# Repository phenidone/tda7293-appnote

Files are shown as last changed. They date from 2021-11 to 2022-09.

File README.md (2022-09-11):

# Stereo TDA7293

This is a PCB design for a stereo amplifier, using a TDA7293 for each channel.

## Power

The board requires 36+36V DC for 8R loads.  Filtering caps are included, but 
a bridge rectifier is not as this is expected to be used with a switching supply.

## Unmute

The muting circuits are controlled via an opto-isolated input.  Provide 
5-24VDC on the UNMUTE port to enable the amplifiers.  This port allows the
amplifier to be put into a standby/mute mode, e.g. while preamplifiers are
booting and power supplies are stabilising.

## Components

Input capacitors shall be film-type box capacitors, 5mm lead pitch.

C3 and C9 should be non-polarised 22uF electrolytics, as high-voltage as will
fit in the footprint (8mm with 3.5mm lead pitch).

All resistors in the signal chain (R1, R2, R3, R13, R14, R15) should be thin-film
metal precision resistors.

Loop-break resistors (R7, R8, R17, R18) can be chosen differently in accordance
with different grounding needs, e.g. where multiple modules are powered from a
single PSU but receiving signal from a third preamplifier board.  Their
selection depends on your ground topology.

The output zobels (R5/C6, R16/C12) are probably only necessary with a TDA7294,
and may be omitted if there is absolutely no chance of shorting the amplifier
leads, e.g. through use of insulated plugs instead of bare wires into screw
terminals.  R5 and R16 should be 2W-rated.

## TDA7294

The board charges the bootstrap capacitor from the OUTPUT pin rather than
the BOOTLOAD pin, so this board will also work unmodified with a TDA7294.
That limits the absolute-max supply voltage to 100V rather than 120V, but
the appropriate level is lower than that anyway unless you have a very high
impedance load.

## License

This hardware design is (C) 2021 William Brodie-Tyrrell and is licensed under 
the CERN OHL; see cern_ohl_v_1_2.pdf

## TRL

Rev.A is tested and working, but has not been subjected to EMI or other
regulatory testing.

Rev.B has been manufactured but not tested.

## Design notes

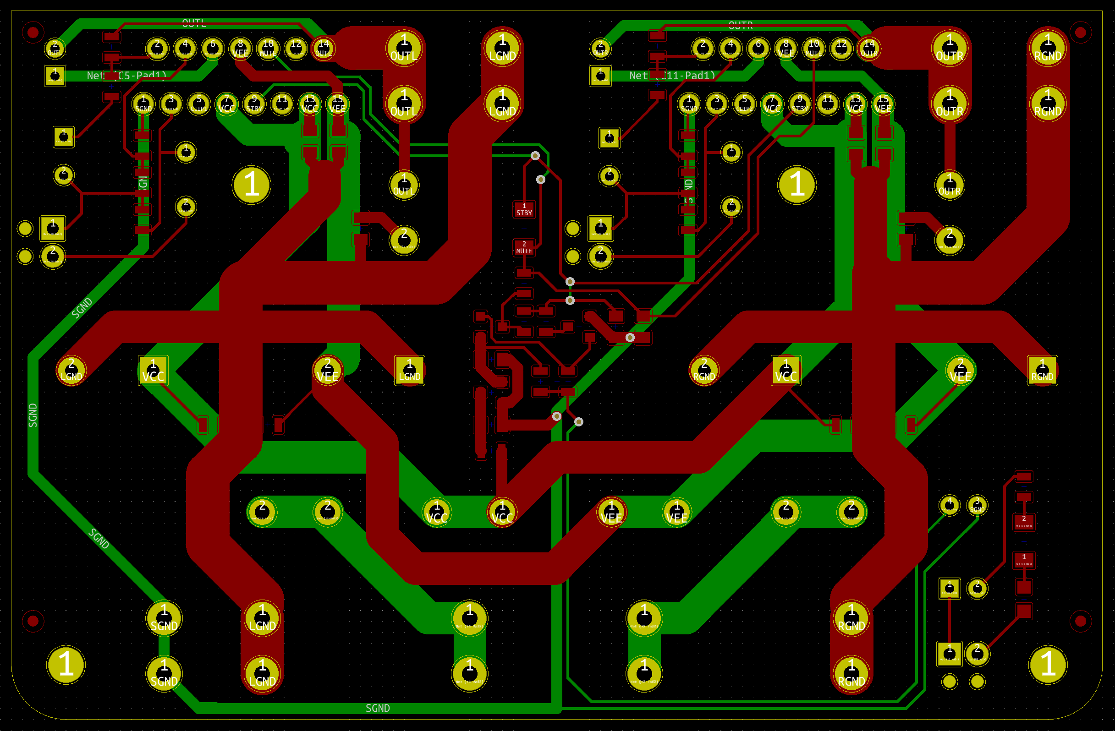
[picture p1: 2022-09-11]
tda7293-layout.png

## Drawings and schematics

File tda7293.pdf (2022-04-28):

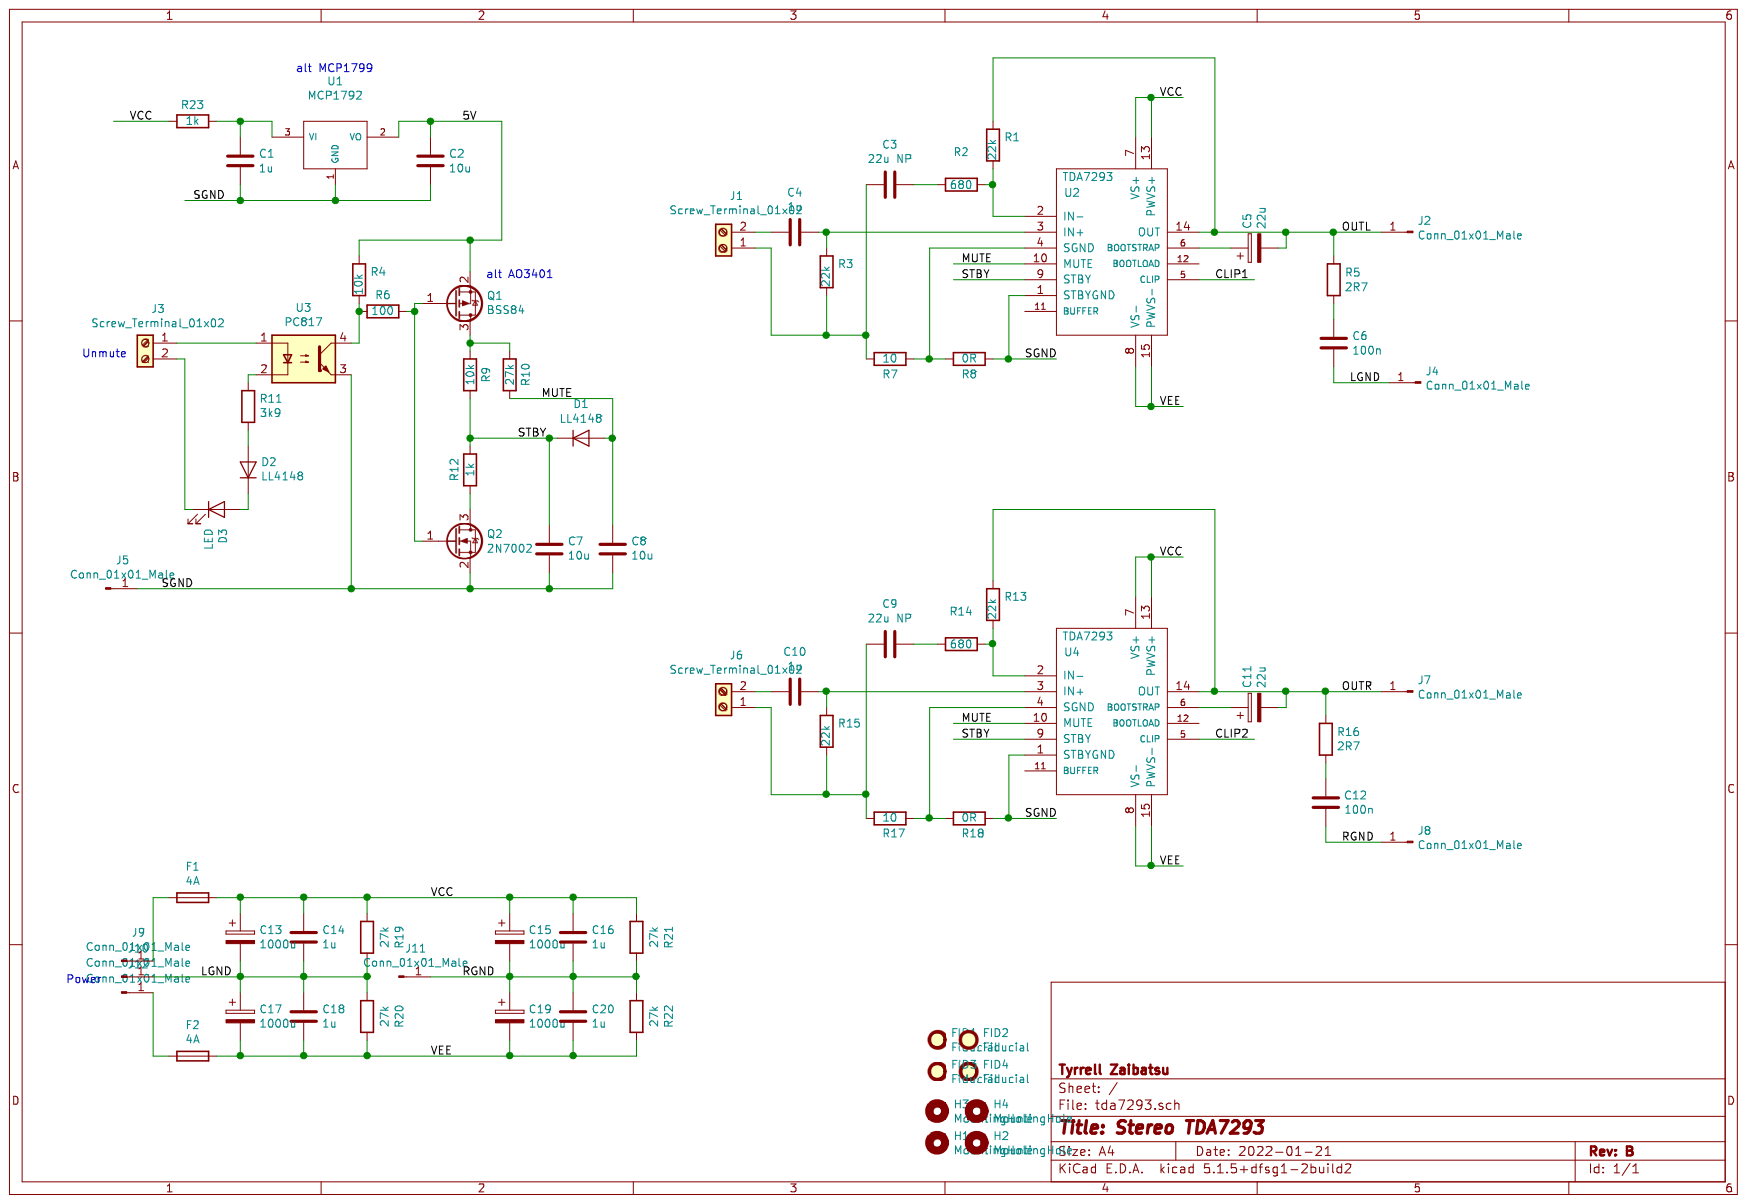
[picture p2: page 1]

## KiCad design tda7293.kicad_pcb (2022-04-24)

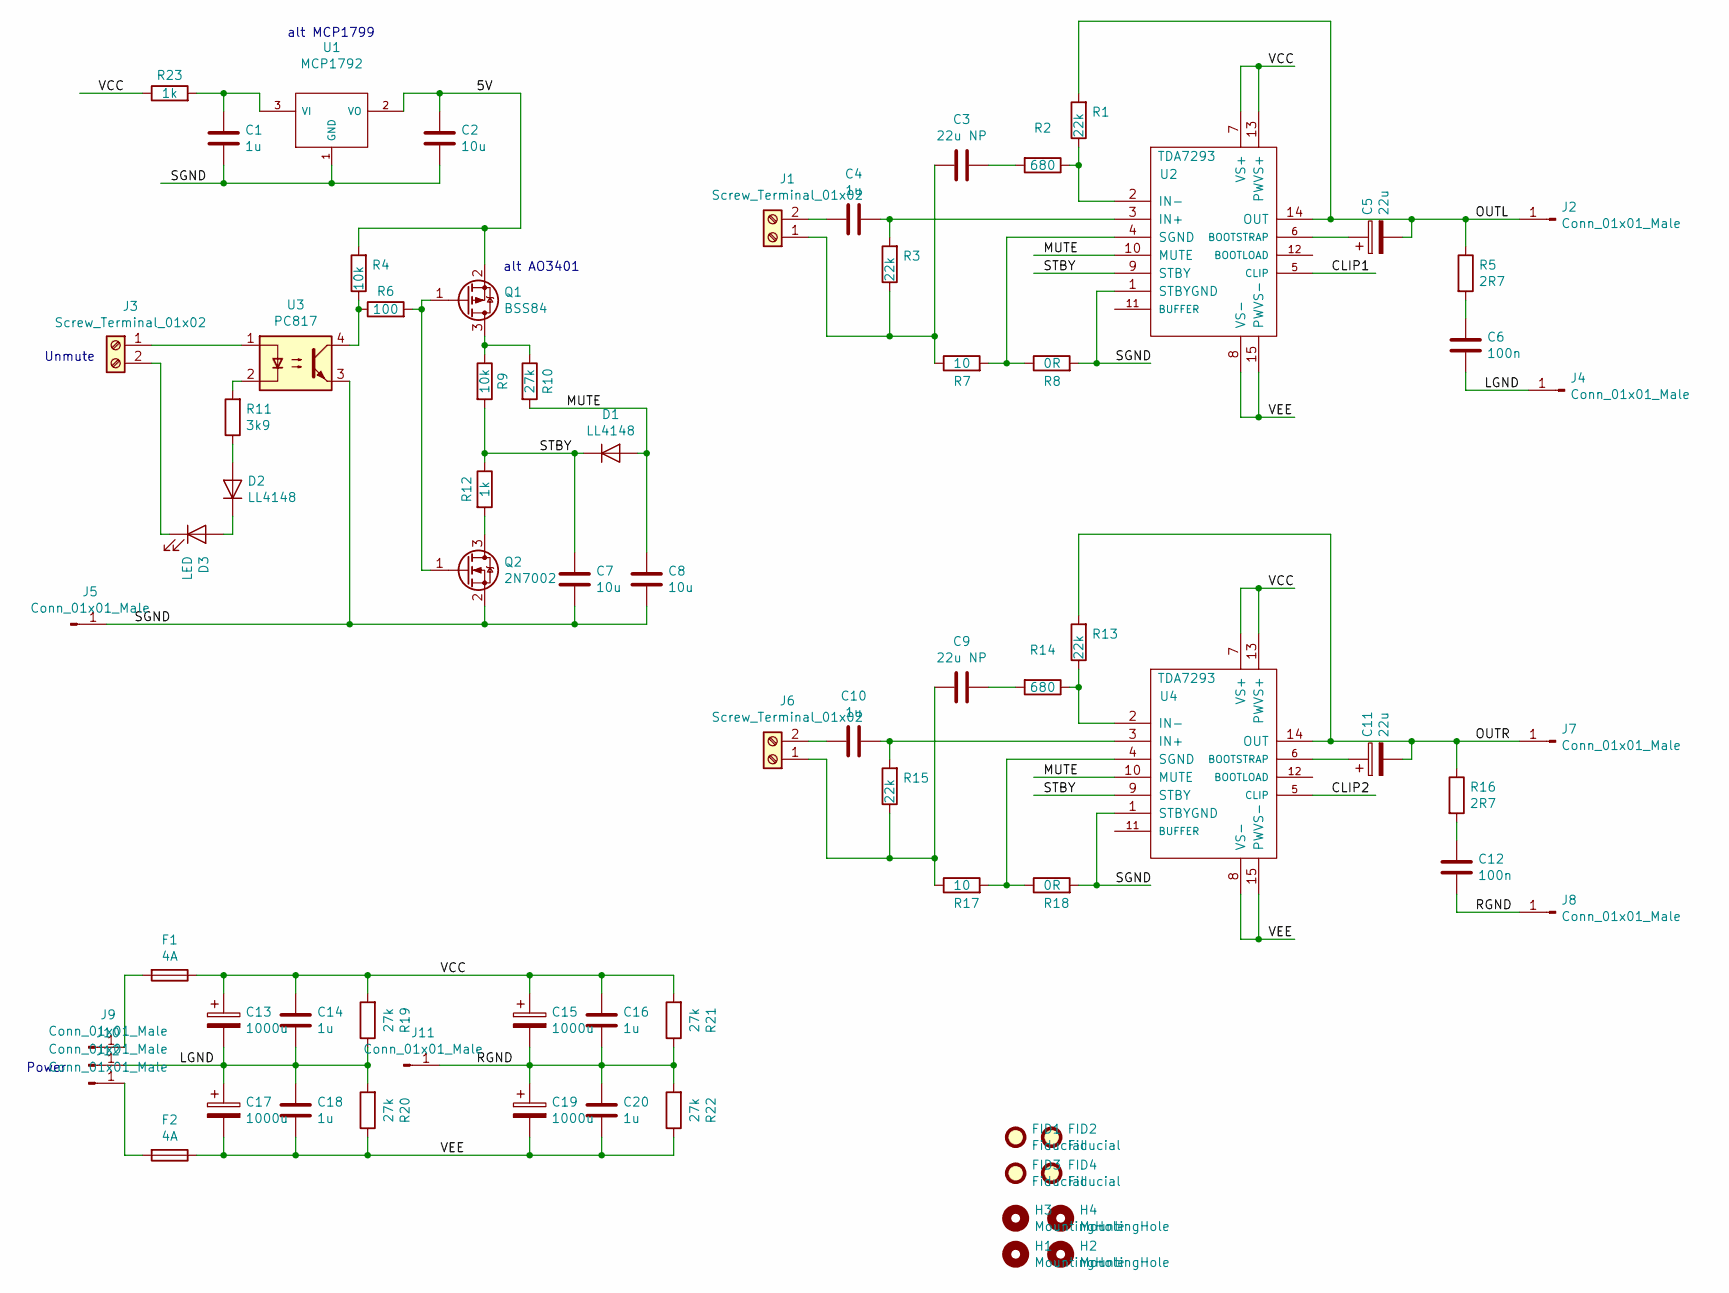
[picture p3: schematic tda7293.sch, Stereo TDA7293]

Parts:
C1, C14, C16, C18, C20: 1u; C_0805
C2, C7, C8: 10u; C_0805
C3, C9: 22u NP; CP_Radial_D8.0mm_P3.50mm
C4, C10: 1u; C_Rect_L7.0mm_W3.5mm_P5.00mm
C5, C11: 22u; CP_Radial_D6.3mm_P2.50mm
C6, C12: 100n; C_0805
C13, C15, C17, C19: 1000u; CP_Radial_D16.0mm_P7.50mm
D1, D2: LL4148; D_MiniMELF
D3: LED; LED_0805
F1, F2: 4A; Fuseholder5x20_6mm
FID1, FID2, FID3, FID4: Fiducial; Fiducial_1mm_Dia_2mm_Outer
H1, H2, H3, H4: MountingHole; MountingHole_3.2mm_M3
J1, J3, J6: Screw_Terminal_01x02; TerminalBlock_Phoenix_MPT-2.54mm_2pol
J2, J4, J5, J7, J8, J9, J10, J11, J12: Conn_01x01_Male; FASTON250P_5.08mm_male_vertical
Q1: BSS84; SOT-23
Q2: 2N7002; SOT-23
R1, R3, R13, R15: 22k; R_0805
R2, R14: 680; R_0805
R4, R9: 10k; R_0805
R5, R16: 2R7; R_Axial_DIN0414_L11.9mm_D4.5mm_P5.08mm_Vertical
R6: 100; R_0805
R7, R17: 10; R_0805
R8, R18: 0R; R_0805
R10, R19, R20, R21, R22: 27k; R_0805
R11: 3k9; R_0805
R12, R23: 1k; R_0805
U1: MCP1792; SOT-23
U2, U4: TDA7293; Multiwatt15V
U3: PC817; DIP-4_W7.62mm_Socket

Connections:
/5V: C2.1, Q1.2 (S), R4.2, U1.2 (VO)
/CLIP1: U2.5 (CLIP)
/CLIP2: U4.5 (CLIP)
/LGND: C6.2, C13.2, C14.2, C17.1, C18.1, J4.1, J10.1, R19.1, R20.2
/MUTE: C8.2, D1.2 (A), R10.2, U2.10 (MUTE), U4.10 (MUTE)
/OUTL: C5.2, J2.1, R1.2, R5.1, U2.14 (OUT)
/OUTR: C11.2, J7.1, R13.2, R16.1, U4.14 (OUT)
/RGND: C12.2, C15.2, C16.2, C19.1, C20.1, J8.1, J11.1, R21.1, R22.2
/SGND: C1.2, C2.2, C7.1, C8.1, J5.1, Q2.2 (S), R8.2, R18.2, U1.1 (GND), U2.1 (STBYGND), U3.3, U4.1 (STBYGND)
/STBY: C7.2, D1.1 (K), R9.2, R12.1, U2.9 (STBY), U4.9 (STBY)
/VCC: C13.1, C14.1, C15.1, C16.1, F1.1, R19.2, R21.2, R23.1, U2.7 (VS+), U2.13 (PWVS+), U4.7 (VS+), U4.13 (PWVS+)
/VEE: C17.2, C18.2, C19.2, C20.2, F2.1, R20.1, R22.1, U2.8 (VS-), U2.15 (PWVS-), U4.8 (VS-), U4.15 (PWVS-)
unnamed: C1.1, R23.2, U1.3 (VI)
unnamed: C3.1, R2.2
unnamed: C3.2, J1.1, R3.1, R7.1
unnamed: C4.1, R3.2, U2.3 (IN+)
unnamed: C4.2, J1.2
unnamed: C5.1, U2.6 (BOOTSTRAP)
unnamed: C6.1, R5.2
unnamed: C9.1, R14.2
unnamed: C9.2, J6.1, R15.1, R17.1
unnamed: C10.1, R15.2, U4.3 (IN+)
unnamed: C10.2, J6.2
unnamed: C11.1, U4.6 (BOOTSTRAP)
unnamed: C12.1, R16.2
unnamed: D2.1 (K), D3.2 (A)
unnamed: D2.2 (A), R11.1
unnamed: D3.1 (K), J3.2
unnamed: F1.2, J9.1
unnamed: F2.2, J12.1
unnamed: J3.1, U3.1
unnamed: Q1.1 (G), Q2.1 (G), R6.2
unnamed: Q1.3 (D), R9.1, R10.1
unnamed: Q2.3 (D), R12.2
unnamed: R1.1, R2.1, U2.2 (IN-)
unnamed: R4.1, R6.1, U3.4
unnamed: R7.2, R8.1, U2.4 (SGND)
unnamed: R11.2, U3.2
unnamed: R13.1, R14.1, U4.2 (IN-)
unnamed: R17.2, R18.1, U4.4 (SGND)

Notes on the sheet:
Power
Unmute
alt AO3401
alt MCP1799

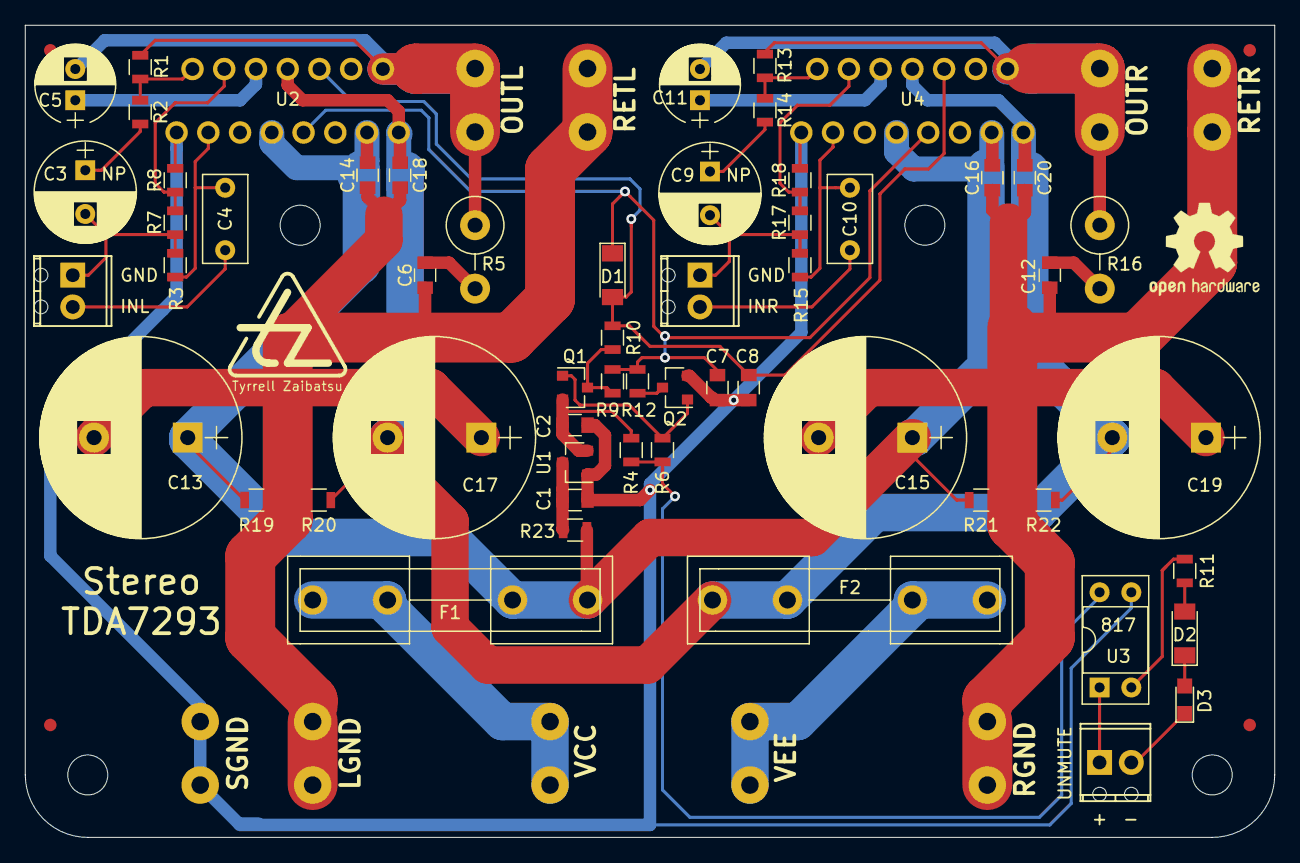
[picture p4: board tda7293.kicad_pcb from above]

Board: 2 copper layers, 100.0 x 65.0 mm, 74 parts (0 on the bottom side), 38 nets.

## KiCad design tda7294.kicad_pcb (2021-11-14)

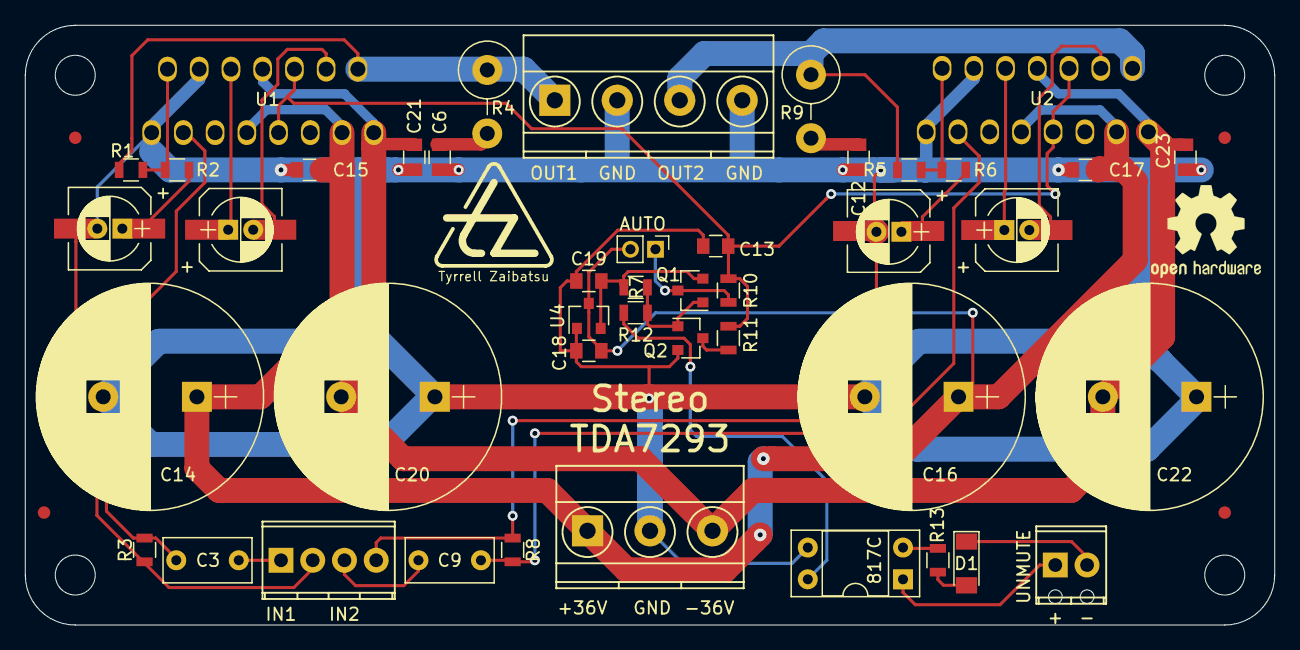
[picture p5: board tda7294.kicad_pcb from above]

Board: 2 copper layers, 100.0 x 48.0 mm, 56 parts (0 on the bottom side), 29 nets.

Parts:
C1, C4, C7, C10: 22u; CP_Elec_6.3x7.7
C2, C5, C8, C11: 22u; CP_Radial_D5.0mm_P2.00mm
C3, C9: 1u; C_Rect_L7.0mm_W3.5mm_P5.00mm
C6, C12: 100n; C_0805
C13, C19: 10u; C_0805
C14, C16, C20, C22: 3300u; CP_Radial_D18.0mm_P7.50mm
C15, C17, C18, C21, C23: 1u; C_0805
D1: LL4148; D_MiniMELF
FID1, FID2, FID3, FID4: Fiducial; Fiducial_1mm_Dia_2mm_Outer
H1, H2, H3, H4: MountingHole; MountingHole_3.2mm_M3
J1: Screw_Terminal_01x04; TerminalBlock_Phoenix_MPT-2.54mm_4pol
J2: Screw_Terminal_01x04; TerminalBlock_Phoenix_MKDS1.5-4pol
J3: Screw_Terminal_01x02; TerminalBlock_Phoenix_MPT-2.54mm_2pol
J4: Screw_Terminal_01x03; TerminalBlock_Phoenix_MKDS1.5-3pol
JP3: Jumper_NO_Small; Pin_Header_Straight_1x02_Pitch2.00mm
Q1: BSS84; SOT-23
Q2: 2N7002; SOT-23
R1, R3, R5, R8: 22k; R_0805
R2, R6: 680; R_0805
R4, R9: 2R7; R_Axial_DIN0414_L11.9mm_D4.5mm_P5.08mm_Vertical
R7, R10: 10k; R_0805
R11: 1k; R_0805
R12: 100; R_0805
R13: 3k9; R_0805
U1, U2: TDA7293; Multiwatt15V
U3: PC817; DIP-4_W7.62mm_Socket
U4: MCP1792; SOT-23

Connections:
/5V: C19.1, Q1.2, R7.2, U4.2
/GND: C1.2, C2.2, C6.2, C7.2, C8.2, C12.2, C13.1, C14.2, C15.2, C16.2, C17.2, C18.2, C19.2, C20.1, C21.1, C22.1, C23.1, J1.2, J1.4, J2.2, J2.4, J4.2, Q2.2, R3.1, R8.1, U1.1, U1.4, U2.1, U2.4, U3.3, U4.1
/MUTE: C13.2, R10.2, R11.2, U1.9, U1.10, U2.9, U2.10
/OUT1: J2.1, R1.2, R4.1, U1.14
/OUT2: J2.3, R5.2, R9.1, U2.14
/VCC: C14.1, C15.1, C16.1, C17.1, C18.1, J4.1, JP3.2, U1.7, U1.13, U2.7, U2.13, U4.3
/VEE: C20.2, C21.2, C22.2, C23.2, J4.3, U1.8, U1.15, U2.8, U2.15
unnamed: C1.1, C2.1, R2.2
unnamed: C3.1, R3.2, U1.3
unnamed: C3.2, J1.1
unnamed: C4.1, C5.1, U1.6
unnamed: C4.2, C5.2, U1.12
unnamed: C6.1, R4.2
unnamed: C7.1, C8.1, R6.2
unnamed: C9.1, R8.2, U2.3
unnamed: C9.2, J1.3
unnamed: C10.1, C11.1, U2.6
unnamed: C10.2, C11.2, U2.12
unnamed: C12.1, R9.2
unnamed: D1.1, J3.2
unnamed: D1.2, R13.1
unnamed: J3.1, U3.1
unnamed: JP3.1, Q1.3, R10.1
unnamed: Q1.1, Q2.1, R7.1, R12.2
unnamed: Q2.3, R11.1
unnamed: R1.1, R2.1, U1.2
unnamed: R5.1, R6.1, U2.2
unnamed: R12.1, U3.4
unnamed: R13.2, U3.2

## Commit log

2021-11-03 drafted PCB for TDA7293/TDA7294
    [tda7294.kicad_pcb, tda7294.sch]
2021-11-14 Re-routed to separate the signal, power and output grounds
    [tda7294.kicad_pcb, tda7294.sch]
2021-11-14 layout turd-polishing, renamed to TDA7293 due to removal of bootstrap jumper
    [tda7293.kicad_pcb, tda7293.sch]
2021-11-20 C substitutions, status LEDs, layout polishing
    [tda7293-B_Cu.gbr, tda7293-B_Mask.gbr, tda7293-B_Paste.gbr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]
2021-11-21 polishing, plotted output, added README
    [tda7293-B_Cu.gbr, tda7293-B_Mask.gbr, tda7293-B_Paste.gbr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]
2021-11-24 removed holes, moved input filters, fancier unmute timing per datasheet
    [tda7293-B_Cu.gbr, tda7293-B_Mask.gbr, tda7293-B_Paste.gbr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]
2021-11-29 moved a resistor, plotted ready for manufacture
    [tda7293-B_Cu.gbr, tda7293-B_Mask.gbr, tda7293-B_Paste.gbr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]
2021-11-29 fixed footprint - matching hole size
    [tda7293-B_Cu.gbr, tda7293-B_Mask.gbr, tda7293-B_Paste.gbr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]
2022-01-23 Redrafted as Rev.B: hum-break resistors, better GND topology, fuses, room for heatsink screwdrivers!
    [tda7293.kicad_pcb, tda7293.sch]
2022-04-24 silk-screen updates, turd-polishing, plotted gerbers
    [tda7293-B_Cu.gbr, tda7293-B_Mask.gbr, tda7293-B_Paste.gbr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]
2022-04-28 plotted, updated schematic pdf
